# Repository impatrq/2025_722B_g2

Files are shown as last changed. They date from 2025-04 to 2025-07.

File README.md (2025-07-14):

# AQUILES - Exoesqueleto de Asistencia Motora

<div align="center">
  Logo Proyecto Aquiles
  <h3>Revolucionando la movilidad humana</h3>
  <p>Exoesqueleto de asistencia motora con inteligencia artificial</p>
  
  <!-- Íconos de redes sociales -->
<p align="center">
  <a href="https://www.instagram.com/misaacas" target="_blank" style="text-decoration: none; outline: none;">
    Instagram
  </a>&nbsp;&nbsp;&nbsp;&nbsp;
  <a href="https://www.linkedin.com/in/misael-castillo-0a52a1314/" target="_blank" style="text-decoration: none; outline: none;">
    LinkedIn
  </a>&nbsp;&nbsp;&nbsp;&nbsp;
  <a href="https://www.youtube.com/" target="_blank" style="text-decoration: none; outline: none;">
    YouTube
  </a>&nbsp;&nbsp;&nbsp;&nbsp;
  <a href="https://www.tiktok.com/" target="_blank" style="text-decoration: none; outline: none;">
    TikTok
  </a>
</p>
</div>

## 🌐 Accede a la Página Web

🔗 [Visita Aquiles Web](https://aquilesproject.com/)

## ✨ Revolucionando la Movilidad Humana

AQUILES es un exoesqueleto de asistencia motora diseñado para mejorar la movilidad de personas con debilidad muscular, fatiga crónica o dificultades motrices. Este sistema innovador reduce el esfuerzo físico del usuario, permitiendo una marcha más eficiente y menos agotadora.

## 🔧 Características Principales

- **Asistencia Inteligente**: AQUILES integra inteligencia artificial para adaptar su funcionamiento a las necesidades del usuario en tiempo real.
- **Sistema de Ajuste**: Un botón permite regular el nivel de asistencia, facilitando la rehabilitación progresiva y el fortalecimiento muscular.
- **Diseño Ergonómico y Ligero**: Fabricado con materiales resistentes y de bajo peso para garantizar comodidad y facilidad de uso.
- **Sensores Avanzados**: Incluye acelerómetros y encoders para monitorear el movimiento y optimizar la asistencia.
- **Monitor de Salud**: Registra calorías quemadas y mide el pulso mediante un sensor ubicado en la arteria femoral.
- **Aplicaciones en Rehabilitación**: Ideal para programas médicos donde los especialistas pueden ajustar la asistencia según la evolución del paciente.
- **Baterías Intercambiables**: Ofrece una autonomía de 45 minutos con baterías compactas y fáciles de reemplazar.

## 👨‍👩‍👦🛠️ Aplicaciones

- **Personas con movilidad reducida**: AQUILES reduce el esfuerzo necesario para caminar.
- **Personas con sobrepeso o alta estatura**: Ayuda a disminuir la carga en articulaciones y músculos.
- **Adultos mayores**: Facilita la marcha y reduce la fatiga muscular.
- **Rehabilitación física**: Ajuste progresivo para recuperar fuerza y movilidad.
- **Deporte y fitness**: Apoya la resistencia y optimiza el rendimiento físico.

## ⚡ Tecnología Utilizada

- **Hardware**:

  - Raspberry Pi 4
  - Sensores de aceleración y encoders
  - Motores brushless con controladores ESC
  - Baterías LiPo 3S 5000mAh 70C
  - Pulsadores y sistema de ajuste de asistencia

- **Software**:
  - Programación en C/C++ y Python
  - Algoritmos de Machine Learning para optimización de asistencia
  - Integración con microcontroladores RP2040
  - Flutter para la aplicación móvil
  - Firebase para la base de datos

## 💸 Costos Estimados

El desarrollo de AQUILES tiene un costo estimado de **378 USD**, incluyendo componentes electrónicos, motores y materiales de fabricación.

## 📢 Contribución

Si deseas colaborar con el desarrollo de AQUILES, puedes contribuir con:

- Mejoras en el código
- Optimización de hardware
- Documentación y pruebas
- Aportes económicos para investigación y desarrollo

## 🛠️ Instalación y Uso

1. Clona el repositorio:
   ```bash
   git clone https://github.com/tu-usuario/aquiles.git
   ```
2. Instala las dependencias necesarias.
3. Carga el firmware en la Raspberry Pi 4.
4. Conecta los motores y sensores.
5. Ajusta el nivel de asistencia y comienza a probar AQUILES.

## 📈 Futuro del Proyecto

- Implementación de algoritmos de IA más avanzados.
- Desarrollo de una aplicación móvil para el monitoreo en tiempo real.
- Optimización del consumo energético para aumentar la autonomía.
- Pruebas con usuarios reales para mejorar la experiencia de uso.

## Integrantes:

### Juan Montilla

- 📷 Instagram: [@montillajuanignacio](https://www.instagram.com/montillajuanignacio/)
- 📧 Mail: montillajuanignacio@gmail.com
- 🏆 LinkedIn:[Juan Montilla](https://www.linkedin.com/in/juan-ignacio-montilla-b98064358/)
- 🌐 Github: [@monti3](github.com/monti3)

### Santiago Alberto Zacarías

- 📷 Instagram: [@santizaca\_](https://www.instagram.com/santizaca_/)
- 📧 Mail: sanfran120771@gmail.com
- 🏆 LinkedIn: [Santiago Zacarias](https://www.linkedin.com/in/santiago-zacar%C3%ADas-3a3978319/)
- 🌐 Github: [ZaCoso](https://github.com/ZaCoso)

### Juan Cruz Isola

- 📷 Instagram: [@juanisola\_](https://www.instagram.com/juanisola_/)
- 📧 Mail: juancruz.isola2209@gmail.com
- 🏆 LinkedIn: [Juan Cruz Isola](https://www.linkedin.com/in/juan-cruz-isola-11309035a/)
- 🌐 Github: [juanisola\_](https://github.com/juanisola)

### Rodrigo Alexis Lin

- 📷 Instagram: [@alexisrodrigolin](https://www.instagram.com/alexisrodrigolin/)
- 📧 Mail: alexisrodrigolin@gmail.com
- 🏆 LinkedIn: [Rodrigo Alexis Lin](https://www.linkedin.com/in/rodrigo-lin-61210a35b/)
- 🌐 Github: [alexisrodrigolin](https://github.com/alexisrodrigolin)

### Mauricio Trillo Contardi

- 📷 Instagram: [@mauritrillo\_](https://www.instagram.com/mauritrillo_/)
- 📧 Mail: trillocontardimauricio@gmail.com
- 🏆 LinkedIn: [Mauricio Contardi Trillo](https://www.linkedin.com/in/mauricio-trillo-contardi-68bbba35a/)
- 🌐 Github: [Mauriciotrillo](https://github.com/MauricioTrillo)

### Misael Castillo

- 📷 Instagram: [@misaacas](https://www.instagram.com/misaacas/)
- 📧 Mail: misacastillo08@gmail.com
- 🏆 LinkedIn: [Castillo Misael](https://www.linkedin.com/in/misael-castillo-0a52a1314/)
- 🌐 Github: [misaacastillo](https://github.com/misaacastillo)

---

AQUILES es más que un proyecto tecnológico: es una solución que redefine la movilidad humana. ¡Sé parte de la revolución! 💪🛠️

## 📜 Licencia

Este proyecto está licenciado bajo la [MIT License](LICENSE).  
© 2025 Aquiles.corp.

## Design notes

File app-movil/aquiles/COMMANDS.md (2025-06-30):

# 📡 Protocolo de Comunicación BLE - Exoesqueleto

Este documento define el protocolo de comandos utilizado para establecer comunicación entre una aplicación móvil (iOS/Android) y un exoesqueleto controlado mediante un ESP32 utilizando Bluetooth Low Energy (BLE). El objetivo principal es facilitar tanto la telemetría como el ajuste en tiempo real del nivel de asistencia.

---

## 📦 Formato General del Comando

Todos los comandos BLE enviados desde la app deben cumplir el siguiente formato:

COMANDO:VALOR

- **Separador**: `:` (dos puntos)
- **COMANDO**: Código corto en mayúsculas que identifica la acción
- **VALOR**: Puede ser un número, una palabra clave o el signo `?` para consultas

---

## 📘 Comandos Disponibles

| Comando | Descripción | Valor esperado | Ejemplo | Notas |
| --- | --- | --- | --- | --- |
| `AID` | Nivel de asistencia del exo | Entero entre 0 y 100 (%) | `AID:80` | Ajusta el porcentaje de ayuda muscular |
| `ON` | Encender el sistema | `1` | `ON:1` | Activa los motores y sensores principales |
| `OFF` | Apagar el sistema | `1` | `OFF:1` | Detiene todos los sistemas del exoesqueleto |
| `CAL` | Iniciar calibración | `1` | `CAL:1` | Ejecuta la rutina de calibración inicial |
| `SPD` | Velocidad de asistencia | Entero entre 0 y 100 | `SPD:30` | Afecta la respuesta dinámica en ciertos modos |
| `MODE`  | Modo operativo | `AUTO`, `MANU`, `DEMO` | `MODE:AUTO` | Cambia el modo de funcionamiento |
| `BAT` | Consulta de batería | `?` | `BAT:?` | Devuelve el porcentaje de batería restante |
| `STA` | Estado general del sistema  | `?` | `STA:?` | Devuelve información sobre el estado actual |

---

## 📥 Respuestas del ESP32

El ESP32 responde con el mismo formato de texto plano:

| Tipo  | Ejemplo | Descripción |
| ----- | --- | --- |
| `OK`  | `OK:AID SET TO 80` | Comando recibido y ejecutado correctamente  |
| `ERR` | `ERR:VAL OUT OF RANGE` | Error al interpretar o aplicar el comando |
| `BAT` | `BAT:76` | Porcentaje actual de batería |
| `STA` | `STA:OK` o `STA:ERR1`  | Estado general o código de error específico |

---

## 🧪 Ejemplo de Flujo

```plaintext
APP → ESP32:    ON:1
ESP32 → APP:    OK:SYSTEM ON

APP → ESP32:    AID:65
ESP32 → APP:    OK:AID SET TO 65

APP → ESP32:    BAT:?
ESP32 → APP:    BAT:82
```

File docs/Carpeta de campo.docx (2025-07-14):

Carpeta de Campo - Aquiles Project

Integrantes:

Castillo Misael

Isola Juan Cruz

Lin Rodrigo

Montilla Juan Ignacio

Trillo Contardi Mauricio

Zacarias Santiago

Fecha de inicio: 14/04/2025

Bitácora

--------------------------------------------------------------------------------------------------Semana del 10/03

11/03:

● Anteproyecto

12/03

● Anteproyecto

13/03

● Anteproyecto

--------------------------------------------------------------------------------------------------Semana del 17/03

18/03:

● Primer diseño de logo

Ideas:

La A de Aquiles

Las patas de la A = piernas

Detalles blancos que asemejan una prótesis

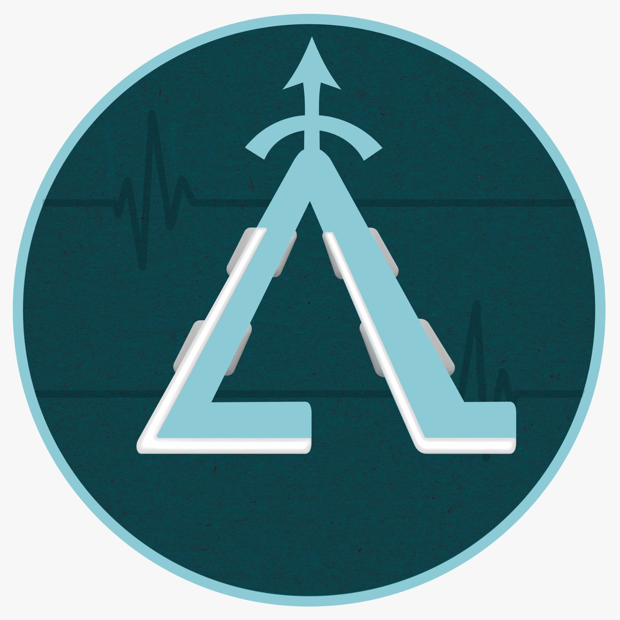
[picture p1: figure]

● Búsqueda de fabricantes de PCB

20/03:

● Configuración de cuentas y perfiles en Github

21/03:

● Investigación de dispositivos similares

● Búsqueda de empresas como posibles sponsor

--------------------------------------------------------------------------------------------------Semana del 24/03

25/03:

● Explicacion e introduccion al sistema scrum

28/03:

● Investigacion y busqueda de componentes y materiales

● Ordenamiento del área de trabajo

--------------------------------------------------------------------------------------------------Semana del 31/03

01/04:

● Recibimos la aprobación del anteproyecto, lo que nos permite oficialmente empezar a trabajar de lleno en el proyecto en sí

● Confección de una lista de posibles sponsor y redacción del mail para contactar con los mismos

04/04:

● Configuración de tablero y cuentas de Trello

● Nos enfocamos en armar nuestros perfiles de LinkedIn, y cuentas del proyecto en Instagram, TikTok y otras plataformas relevantes para establecer nuestra presencia en línea

● Inicio del desarrollo de la página web del proyecto

05/04:

● Investigación y búsqueda de componentes y materiales

● Como parte de nuestra investigación en machine learning e inteligencia artificial, estudiamos y aplicamos los algoritmos básicos de TensorFlow para sentar las bases en este campo. Este aprendizaje nos permitió introducirnos de manera práctica en el desarrollo de modelos de inteligencia artificial.

--------------------------------------------------------------------------------------------------Semana del 07/04

08/04:

● Contacto vía mail con empresas buscando un posible sponsor

● Primer diseño 3D de modelo de engranaje planetario

09/04:

● Se compró un dominio a nombre del proyecto para nuestra futura página web

● Se tomó la decisión de cambiar la dirección de correo del proyecto, pasando de una dirección de Gmail a una de nuestro dominio propio a fin de tener un contacto más profesional.

● Contacto vía mail con empresas buscando un posible sponsor

--------------------------------------------------------------------------------------------------Semana del 14/04

15/04:

● Inicio del desarrollo de la aplicación móvil

● Contacto vía mail con empresas buscando posible sponsor

16/04:

● Desarrollo de la aplicación móvil del proyecto

● Primera publicación en Instagram presentando el proyecto y a nuestro equipo

● Contacto vía mail con empresas buscando posible sponsor

--------------------------------------------------------------------------------------------------Semana del 21/04

22/04:

● Primera versión de la página web finalizada y publicada usando el dominio del proyecto

● Inicio de diseño 3D del primer prototipo del módulo de asistencia motriz

23/04:

● Elaboramos las historias de usuario

● Nos comunicamos con el centro de rehabilitación de Quilmes a fin de coordinar una reunión para hablarles de nuestro proyecto

- Tras evaluar los recursos limitados del microcontrolador, decidimos cambiar nuestro enfoque: migramos de TensorFlow a Scikit-learn para optimizar el rendimiento y adaptarnos mejor a las capacidades del microcontrolador.

--------------------------------------------------------------------------------------------------Semana del 28/04

29/04:

● Primera presentación del proyecto a nuestros compañeros y docentes

● El centro de ojos de Quilmes se puso en contacto con nosotros para hacernos una donación monetaria, la cual usaremos para comprar los componentes más caros en el exterior a un mejor costo

30/04:

● Se hizo la lista de componentes y se calculó el presupuesto del proyecto

● Desarrollo de la aplicación móvil

● Diseño 3D del módulo de asistencia motriz

--------------------------------------------------------------------------------------------------Semana del 05/05

06/05:

● Debido a un paro de transporte no hubo actividad escolar

07/05:

● Se realizó un ajuste estético en la cuenta de Instagram con el objetivo de unificar la identidad visual del proyecto en todas las plataformas. La estética anterior difería del estilo aplicado en la página web y en la aplicación móvil, por lo que se optó por eliminar la primera publicación y reemplazarla por una nueva que respeta el formato y paleta de colores definido para nuestras plataformas digitales.

● Diseño 3D del módulo de asistencia motriz

--------------------------------------------------------------------------------------------------Semana del 12/05

13/05:

● Prácticas profesionalizantes en Newton.

● Se realizó la compra de los motores directamente desde china con la donación del centro de ojos

● Se coordinó una reunión con la directora ejecutiva del centro de rehabilitación de Quilmes para el día
14/05:

● Se trabajó en la preparación de la presentación y el pitch que se utilizarán en la próxima reunión. El contenido incluye una explicación general del proyecto, nuestros objetivos y el acompañamiento que buscamos en ellos como sponsor.

15/05:

● Tuvimos una reunión con la directora ejecutiva en el centro de rehabilitación de Quilmes que duró toda la mañana, donde conseguimos que se interesen en el proyecto y nos ofrecieron tanto apoyo económico, como acompañamiento por parte de profesionales del entorno de la rehabilitación muscular.

● Fuimos a Microcentro a comprar algunos de los componentes requeridos.

--------------------------------------------------------------------------------------------------Semana del 19/05

19/05:

● Video para la cuenta de Instagram anunciando al centro de ojos como nuestro sponsor oficial

20/05:

● Prácticas profesionalizantes en Newton.

● Curso en la UTN.

23/05:

● Coordinar con la CM del centro de rehabilitacion para crear un video para subir a redes sociales

● Diseño 3D del módulo de asistencia motriz

--------------------------------------------------------------------------------------------------Semana del 26/05

26/05:

● Reunión en el centro de rehabilitación para informarnos sobre los diferentes tipos de tratamientos con profesionales del lugar. Tras hablar con el Dr. Andres Kodysz cambiamos la perspectiva centrada en asistencia motriz y estabilidad a una focalizada exclusivamente en asistencia motriz, especialmente dirigida a personas mayores con debilidad muscular.

27/05:

● Video para la cuenta de instagram anunciando al centro de rehabilitación como nuestro sponsor oficial

● No hubo actividad escolar

● Inicio de el redesign de la página web

30/05:

● Asistimos a la Expo UADE para informarnos sobre las carreras de ingeniería

--------------------------------------------------------------------------------------------------Semana del 02/06

03/06:

● Finalización del diseño 3D del módulo de asistencia motriz

● Impresión 3D del módulo de asistencia motriz previamente diseñado

● Curso en la UTN

● Luego de una larga y enriquecedora discusión llegamos a un acuerdo en el que utilizaremos arduino a la par con un sistema operativo en tiempo. Además, cambiamos el foco de la inteligencia artificial. Pasamos de una IA creada por nosotros a un algoritmo para el movimiento. Sin embargo, utilizaremos MCP (Protocolo de Contexto de Modelo) para crear un chatbot dentro de la aplicación web.

04/06:

● Reunión en el centro de rehabilitación con el director financiero de la institución para discutir aspectos relacionados con costos y presupuesto del proyecto. Además, se mantuvo una conversación con un médico traumatólogo con el fin de profundizar en el conocimiento sobre las lesiones más comunes en los miembros inferiores y su tratamiento.

● Comienzo ajuste y cambie de múltiples parámetros para lanzar el redesign de la página web.

06/06:

● Asistimos al ITBA Future Day para informarnos sobre las carreras de ingeniería, y los programas de becas de la institución.

07/06:

● Publicación de Instagram presentando el módulo de asistencia motriz con sus componentes y capacidades

--------------------------------------------------------------------------------------------------Semana del 09/06

10/06:

● Curso en la UTN

● Miembros del grupo asistieron a una charla en la UADE

● Desarrollo de la aplicación móvil

11/06:

● Se diseñó e imprimió una versión de prueba del brazo de la prótesis, esta fue diseñada solo para probar de manera práctica los sistemas y componentes y no refleja la apariencia final del producto

● Se diseñó la PCB del driver

● Inicio del diseño del cinturón completo

13/06:

● Miembros del grupo fueron a Newton a trabajar en la PCB del driver

● Desarrollo de la aplicación móvil

● Desarrollo del diseño del dispositivo

--------------------------------------------------------------------------------------------------Semana del 16/06

17/06:
● Curso en la UTN

● Testing de comunicaciones BLE del ESP32

18/06:

● Recibimos donaciones de Repuestos Santa Fe y de Decomontaje

● Diseño de historias de Instagram para nuestros sponsors

● Implementación de BLE en la Aplicación Móvil

19/06:

● Historias de Instagram para nuestros viejos y nuevos sponsors, anunciando a Respuestos Santa Fe y Decomontaje

● Recibimos una donación de La Amoladora Service

● Testing de comunicaciones con BLE entre la ESP32 y la Aplicación móvil.

--------------------------------------------------------------------------------------------------Semana del 23/06

23/06:

● Historia de Instagram anunciando a La Amoladora Service como nuestro sponsor oficial

25/06:

● Miembros del grupo fueron a Newton a trabajar en la PCB del driver, la misma se continuó en la escuela más tarde

27/06:

● Llegaron los motores que habíamos pedido desde China.

● Investigación acerca del control FOC.

● Investigación acerca del DRV8301 y librerías relacionadas.

--------------------------------------------------------------------------------------------------Semana del 30/06

01/07:

● Prueba con protoboard de los motores

● Historia de Instagram mostrando los avances

● Se finalizó el diseño 3D del dispositivo

02/07:

● Integrantes del grupo fueron a Newton a terminar la PCB del driver.

● Ensamblaje de prueba del módulo de asistencia motriz

03/07:

● Finalización del redesign de la página web

● Charla con David Yablonskas acerca de la fabricación de PCB en China.

--------------------------------------------------------------------------------------------------Semana del 07/07

08/07:

● Hablamos con Alejandro Heir para concordar el envío de las PCB desde China.

● Prácticas profesionalizantes en la base de fuerza aérea.

● Armado de circuito con la PCB del driver.

● Tras fallas en la PCB, concluimos en usar Gate Drivers de mosfets, un circuito más elemental.

09/07:

● Feriado

● Se empezó el diseño de un driver basado en los IR2110

● Se empezó el diseño de una mainboard basada en la ESP32.

--------------------------------------------------------------------------------------------------Semana del 14/07

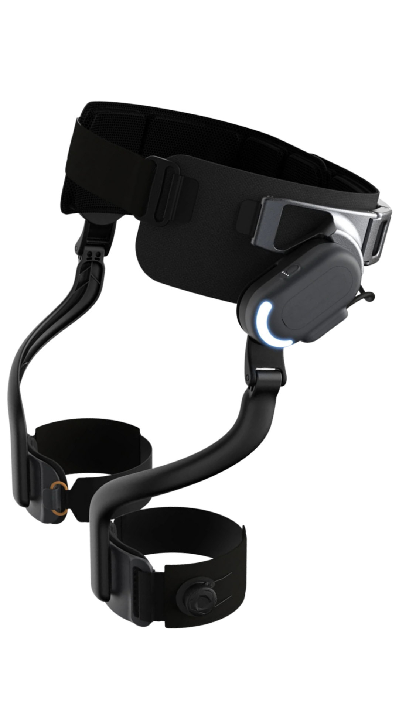
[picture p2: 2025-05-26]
Aquiles_App/aquiles/assets/images/exoesqueleto-1.png

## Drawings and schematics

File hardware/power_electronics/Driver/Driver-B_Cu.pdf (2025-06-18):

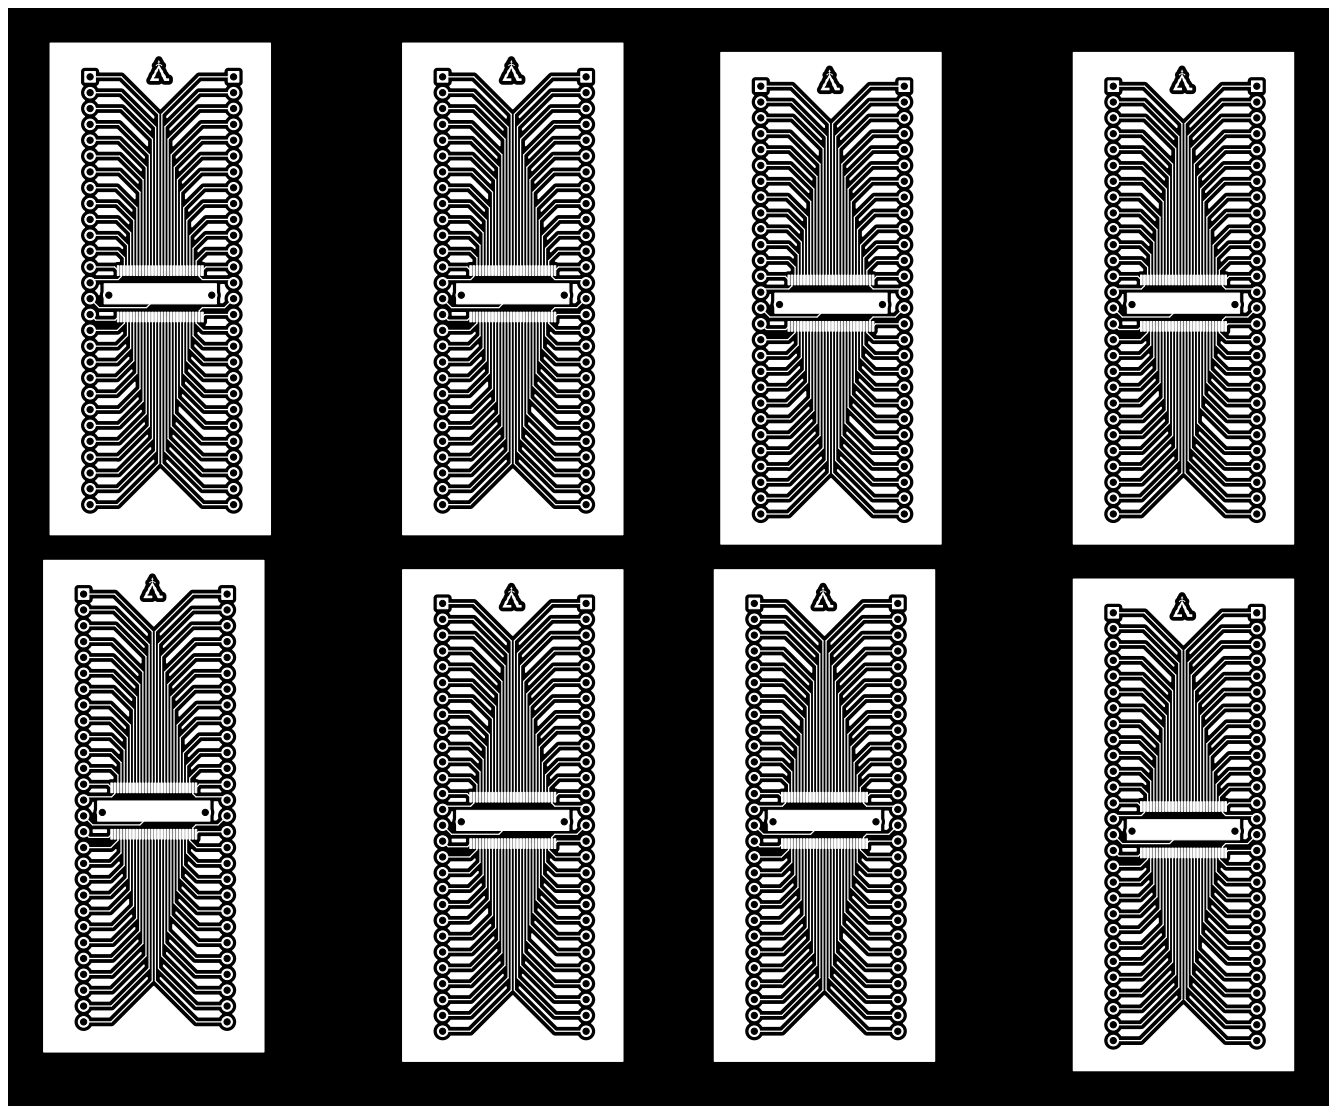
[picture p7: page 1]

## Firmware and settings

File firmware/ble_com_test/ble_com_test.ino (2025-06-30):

#include <BLEDevice.h>
#include <BLEServer.h>
#include <BLEUtils.h>
#include <BLE2902.h>

// Nombre del dispositivo BLE
#define DEVICE_NAME "Aquiles X1"
// UUIDs personalizados
#define SERVICE_UUID        "6e400001-b5a3-f393-e0a9-e50e24dcca9e"
#define CHARACTERISTIC_UUID "6e400002-b5a3-f393-e0a9-e50e24dcca9e"

BLECharacteristic *pCharacteristic;
bool deviceConnected = false;
std::string lastValue = "0";

class MyCallbacks: public BLECharacteristicCallbacks {
    void onWrite(BLECharacteristic *pCharacteristic) {
    std::string value = std::string(pCharacteristic->getValue().c_str());

      if (value.length() > 0) {
        Serial.print("Recibido via BLE: ");
        Serial.println(value.c_str());

        // Por ejemplo, cambiar porcentaje de asistencia
        lastValue = value;
      }
    }
};

class MyServerCallbacks: public BLEServerCallbacks {
    void onConnect(BLEServer* pServer) {
      deviceConnected = true;
      Serial.println("Dispositivo conectado");
    };

    void onDisconnect(BLEServer* pServer) {
      deviceConnected = false;
      Serial.println("Dispositivo desconectado");
    }
};

void setup() {
  Serial.begin(115200);

  BLEDevice::init(DEVICE_NAME);
  
  BLEServer *pServer = BLEDevice::createServer();
  pServer->setCallbacks(new MyServerCallbacks());

  BLEService *pService = pServer->createService(SERVICE_UUID);

  pCharacteristic = pService->createCharacteristic(
    CHARACTERISTIC_UUID,
    BLECharacteristic::PROPERTY_READ   |
    BLECharacteristic::PROPERTY_WRITE  |
    BLECharacteristic::PROPERTY_NOTIFY
  );

  pCharacteristic->addDescriptor(new BLE2902());  // Importante para que Flutter/iOS reciba notificaciones


  pCharacteristic->setValue("0");  // Valor inicial
  pCharacteristic->setCallbacks(new MyCallbacks());
  pService->start();

  BLEAdvertising *pAdvertising = BLEDevice::getAdvertising();
pAdvertising->addServiceUUID(SERVICE_UUID);  // <- ESTA LÍNEA ES CLAVE
pAdvertising->setScanResponse(true);
pAdvertising->start();

  Serial.println("ESP32 BLE listo para conexiones");
}

void loop() {
  // Podés usar el valor recibido:
    static int bat = 0; 
  if (deviceConnected) {
    enviarEstado();
    Serial.println(lastValue.c_str());
    delay(3000); x
  }
}

void enviarEstado() {
  static int bat = 0;
  bat = (bat + 1) % 101;
  String mensaje = "BAT:" + String(bat);
  pCharacteristic->setValue(mensaje.c_str());
  pCharacteristic->notify();

  Serial.print("Enviado: ");
  Serial.println(mensaje);
}

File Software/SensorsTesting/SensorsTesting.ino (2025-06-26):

#include <Wire.h>
#include <MPU6050_light.h>
#include <AS5600.h>

#define SDA_PIN 21
#define SCL_PIN 22

MPU6050 mpu(Wire);   // ✅ Esta sí acepta "Wire"
AS5600 as5600;

void setup() {
  Serial.begin(115200);
  Wire.begin(SDA_PIN, SCL_PIN);
  delay(500);

  Serial.println("🔍 Inicializando sensores...");

  mpu.begin();
  Serial.println("✅ MPU6050 listo");

  as5600.begin();
  as5600.setDirection(AS5600_CLOCK_WISE);
  Serial.println("✅ AS5600 listo");

  mpu.calcOffsets();  // opcional pero mejora lectura
}

void loop() {
  mpu.update();

  Serial.print("Gyro X: ");
  Serial.print(mpu.getGyroX());
  Serial.print(" | Y: ");
  Serial.print(mpu.getGyroY());
  Serial.print(" | Z: ");
  Serial.print(mpu.getGyroZ());

  int angleRaw = as5600.readAngle();
  float degrees = angleRaw * 0.0879;
  Serial.print(" | Encoder: ");
  Serial.print(degrees, 2);
  Serial.println("°");

  delay(200);
}

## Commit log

2025-04-09 refactor: reordeno carpetas de assets
2025-04-09 style: cambio ui de login
2025-04-09 style: cmabio de estilo de la home con implementacion de tabbars
2025-04-09 feat: creo tab de status
2025-04-09 anado tab de rendimiento
2025-04-09 feat: anado tab de config
2025-04-10 fix: cambia enlace de la web
2025-05-26 fix: solucion stop en transicion de login a home
2025-05-26 fix: corrijo el user model
2025-05-26 feat: anado screen de perfil
2025-06-16 feat: creo tab de unconneted y bleservice
2025-06-16 feat: implemento boton para interactuar con BLEservice
2025-06-16 refactor: implemento providers para ble y status ble
2025-06-16 feat: se le envian commandos al dispositivo y .md de los commandos
2025-06-16 refactor: implemento formato de comandos en settings
2025-06-16 feat: incluyo capacidades de recibir desde la app
2025-06-16 feat: anado archivo test ble esp32
2025-06-18 feat: make adapter for DVR8301
    [Driver.kicad_pcb, Driver.kicad_sch]
2025-06-22 feat: make Sensors testing .ino
2025-06-26 fix: mpu not reading bug
    [SensorsTesting.ino]
2025-06-30 refactor: cambiar nombre de directore
2025-07-03 fix: drv footprint correction
    [Driver.kicad_pcb, Driver.kicad_sch]
2025-07-03 chore: rename folders
    [Driver.kicad_pcb, Driver.kicad_sch]
2025-07-14 chore: borro aux.txt
    Se borra este archivo porque causa conflictos en windows a la hora de clonar el repo
2025-07-14 docs: agrego carpeta de campo
2025-07-15 feat: power board
    [Aquiles PCB.kicad_pcb, Aquiles PCB.kicad_sch, Driver.kicad_pcb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]
